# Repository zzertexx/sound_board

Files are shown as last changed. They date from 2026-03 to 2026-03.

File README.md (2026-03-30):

# Soundboard — 16-key Macropad

A custom 16-key macropad built with a Seeed Studio XIAO RP2040, per-key LEDs, and a 0.91" OLED display. Made for [Hack Club](https://hackclub.com/).

---

## Features

- 16 MX-compatible switches in a 4×4 matrix
- Per-key SK6812 MINI-E RGB LEDs
- 0.91" OLED display
- Seeed Studio XIAO RP2040 microcontroller
- QMK firmware
- 3D printed case with sandwitch mounting

---

## Bill of Materials

| Component | Quantity |
|---|---|
| Seeed Studio XIAO RP2040 | 1 |
| MX-style switches | 16 |
| 1N4148 diodes | 16 |
| SK6812 MINI-E LEDs | 16 |
| 0.91" OLED display | 1 |
| DSA white blank keycaps | 16 |
| Resistor 330 ohms | 1 |
| M3x16mm screws | 4 |
| M3x5x4mm heatset inserts | 4 |

---

## Pin Assignment

| Pin | Signal |
|---|---|
| GP0 (PA02) | Row 0 |
| GP1 (PA4) | Row 1 |
| GP2 (PA10) | Row 2 |
| GP3 (PA11) | Row 3 |
| GP4 (PA8 SDA) | OLED SDA |
| GP5 (PA9 SCL) | OLED SCL |
| GP6 (PB08) | Column 0 |
| GP7 (PB09) | Column 1 |
| GP8 (PA7 SCK) | Column 2 |
| GP9 (PA5 MISO) | Column 3 |
| GP10 (PA6 MOSI) | LED Data |

---

## Schematic & PCB

Designed in KiCad 9.0. All source files are in the PCB directory.

- 4×4 keyboard matrix with diodes
- SK6812 MINI-E LEDs placed on bottom layer under each switch
- OLED connected via I2C
- Resistor on GP10 rail for LED stability

---

## Images

sch
pcb
case
pad

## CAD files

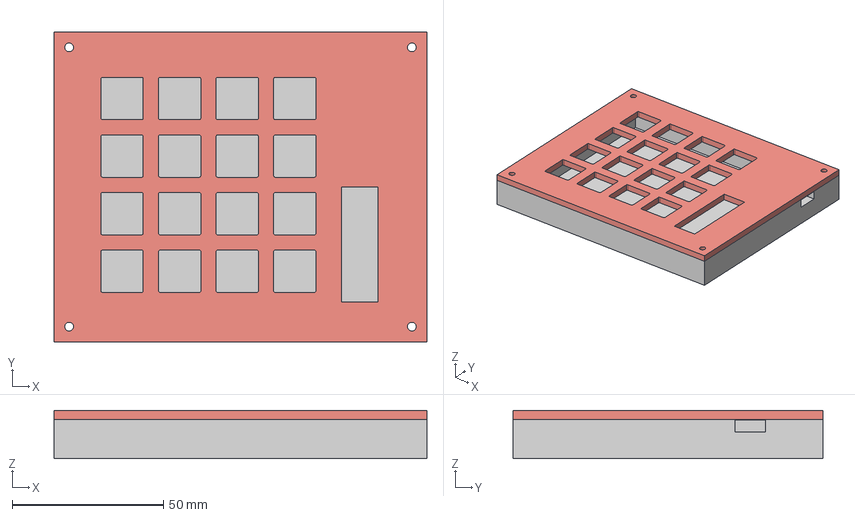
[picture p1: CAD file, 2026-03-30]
CAD/SoundPad.v1.step
123.4 x 102.4 x 16.0 mm

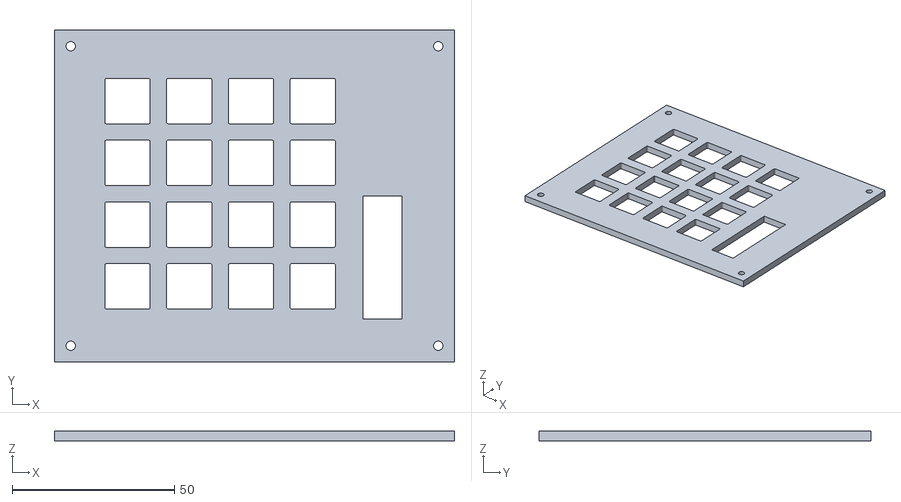
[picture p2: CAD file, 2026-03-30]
production/Plate.stl
123.4 x 102.4 x 3.00

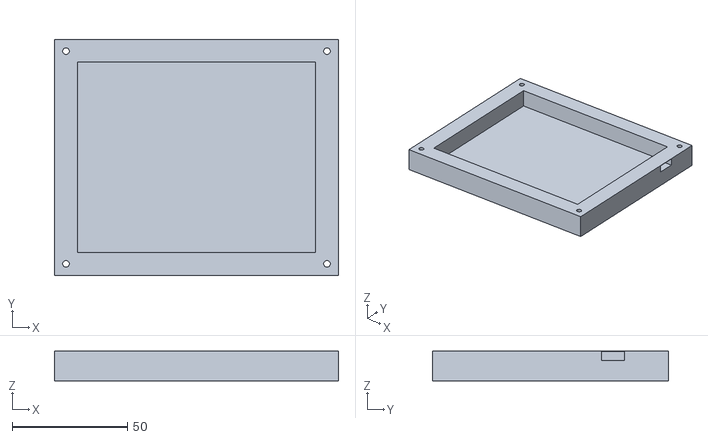
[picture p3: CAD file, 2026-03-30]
production/caseBody.stl
123.4 x 102.4 x 13.0

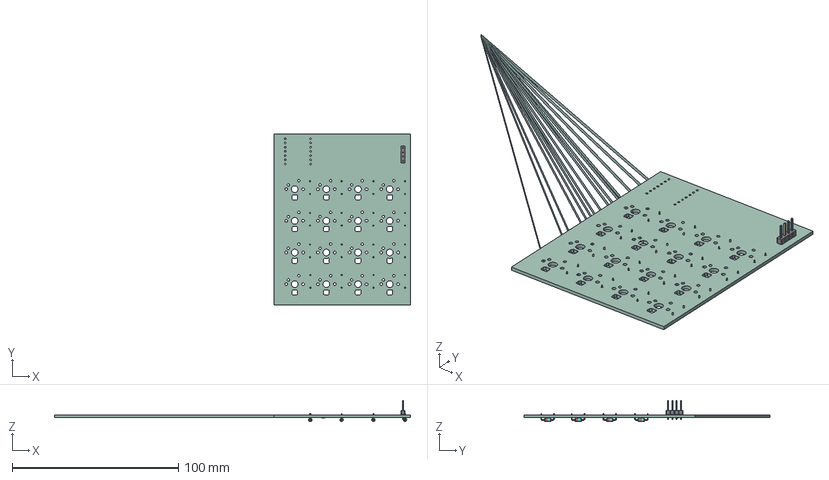
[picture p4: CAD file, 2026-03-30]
production/pcb.step
214.2 x 148.0 x 12.7 mm
PinHeader_1x04_P2.54mm_Vertical
D_DO-35_SOD27_P7.62mm_Horizontal x 16
R_0805_2012Metric
soundboard_PCB

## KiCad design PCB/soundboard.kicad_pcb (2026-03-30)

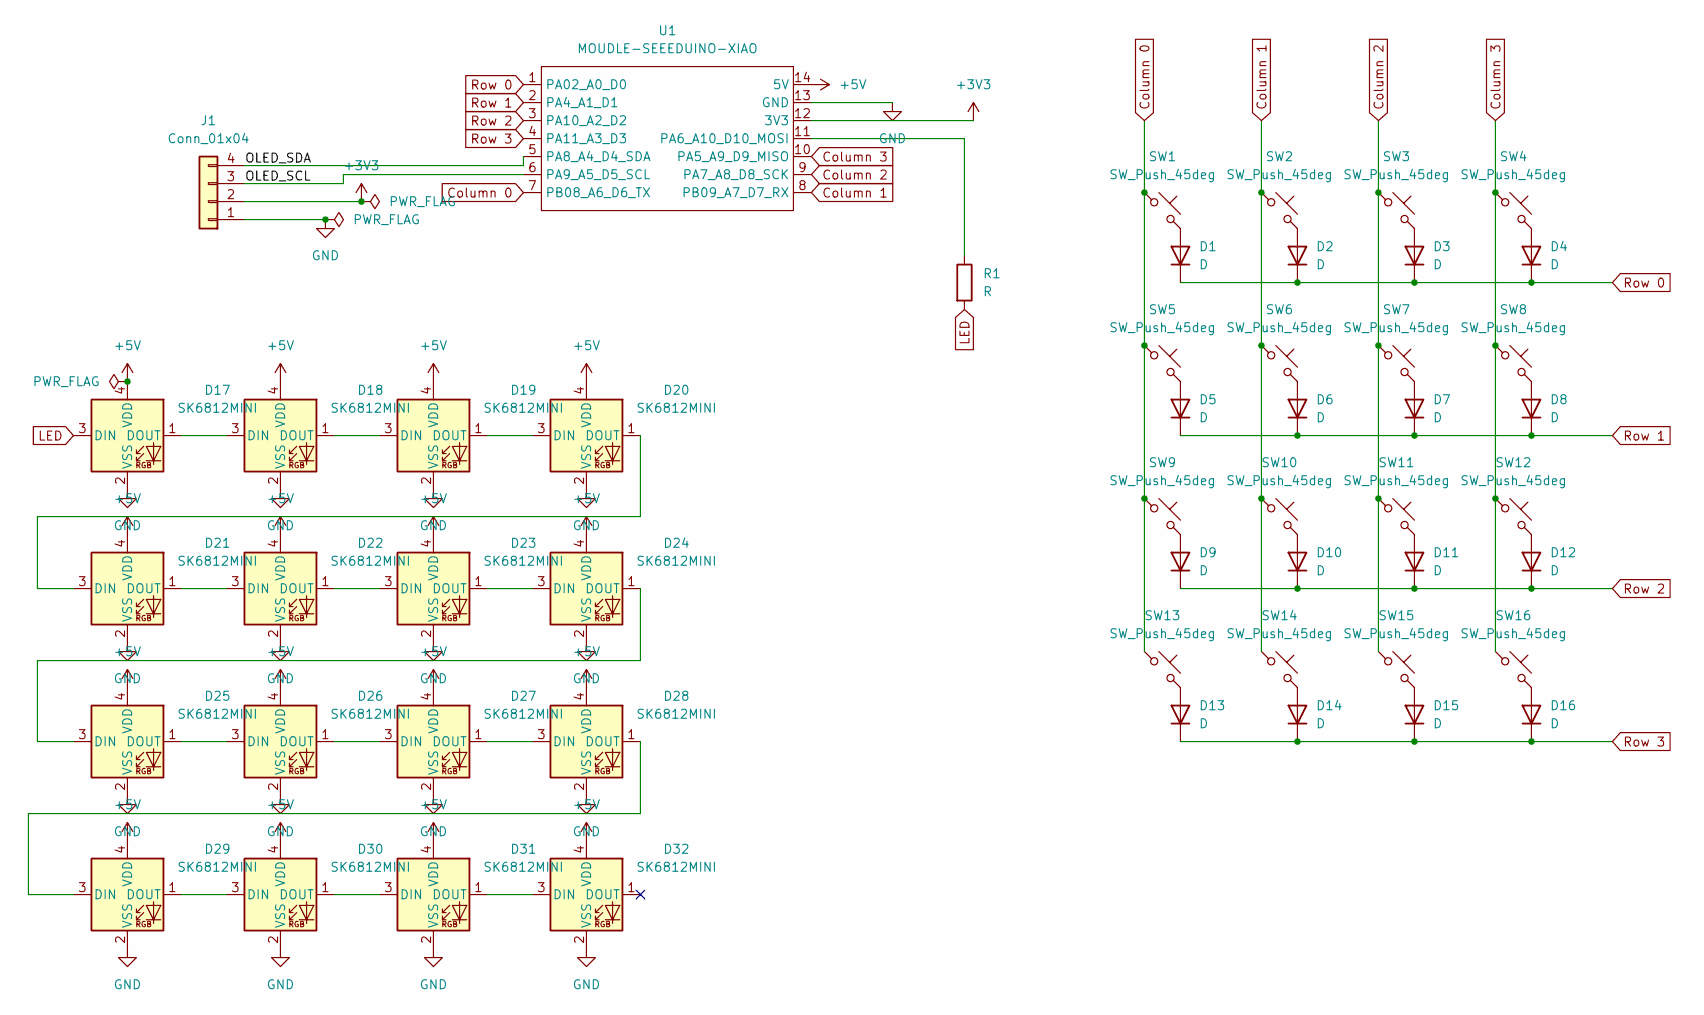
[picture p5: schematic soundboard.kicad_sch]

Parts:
D1, D2, D3, D4, D5, D6, D7, D8, D9, D10, D11, D12, D13, D14, D15, D16: D; D_DO-35_SOD27_P7.62mm_Horizontal
D17, D18, D19, D20, D21, D22, D23, D24, D25, D26, D27, D28, D29, D30, D31, D32: SK6812MINI; SK6812MINI-E_fixed
J1: Conn_01x04; PinHeader_1x04_P2.54mm_Vertical
R1: R; R_0805_2012Metric
SW1, SW2, SW3, SW4, SW5, SW6, SW7, SW8, SW9, SW10, SW11, SW12, SW13, SW14, SW15, SW16: SW_Push_45deg; SW_Cherry_MX_1.00u_PCB
U1: MOUDLE-SEEEDUINO-XIAO; XIAO-Generic-Hybrid-14P-2.54-21X17.8MM

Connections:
+3V3: J1.2, U1.12 (3V3)
+5V: D17.4 (VDD), D18.4 (VDD), D19.4 (VDD), D20.4 (VDD), D21.4 (VDD), D22.4 (VDD), D23.4 (VDD), D24.4 (VDD), D25.4 (VDD), D26.4 (VDD), D27.4 (VDD), D28.4 (VDD), D29.4 (VDD), D30.4 (VDD), D31.4 (VDD), D32.4 (VDD), U1.14 (5V)
/OLED_SCL: J1.3, U1.6 (PA9_A5_D5_SCL)
/OLED_SDA: J1.4, U1.5 (PA8_A4_D4_SDA)
Column 0: SW1.1, SW5.1, SW9.1, SW13.1, U1.7 (PB08_A6_D6_TX)
Column 1: SW2.1, SW6.1, SW10.1, SW14.1, U1.8 (PB09_A7_D7_RX)
Column 2: SW3.1, SW7.1, SW11.1, SW15.1, U1.9 (PA7_A8_D8_SCK)
Column 3: SW4.1, SW8.1, SW12.1, SW16.1, U1.10 (PA5_A9_D9_MISO)
GND: D17.2 (VSS), D18.2 (VSS), D19.2 (VSS), D20.2 (VSS), D21.2 (VSS), D22.2 (VSS), D23.2 (VSS), D24.2 (VSS), D25.2 (VSS), D26.2 (VSS), D27.2 (VSS), D28.2 (VSS), D29.2 (VSS), D30.2 (VSS), D31.2 (VSS), D32.2 (VSS), J1.1, U1.13 (GND)
LED: D17.3 (DIN), R1.2
unnamed: D1.2 (A), SW1.2
unnamed: D2.2 (A), SW2.2
unnamed: D3.2 (A), SW3.2
unnamed: D4.2 (A), SW4.2
unnamed: D5.2 (A), SW5.2
unnamed: D6.2 (A), SW6.2
unnamed: D7.2 (A), SW7.2
unnamed: D8.2 (A), SW8.2
unnamed: D9.2 (A), SW9.2
unnamed: D10.2 (A), SW10.2
unnamed: D11.2 (A), SW11.2
unnamed: D12.2 (A), SW12.2
unnamed: D13.2 (A), SW13.2
unnamed: D14.2 (A), SW14.2
unnamed: D15.2 (A), SW15.2
unnamed: D16.2 (A), SW16.2
unnamed: D17.1 (DOUT), D18.3 (DIN)
unnamed: D18.1 (DOUT), D19.3 (DIN)
unnamed: D19.1 (DOUT), D20.3 (DIN)
unnamed: D20.1 (DOUT), D21.3 (DIN)
unnamed: D21.1 (DOUT), D22.3 (DIN)
unnamed: D22.1 (DOUT), D23.3 (DIN)
unnamed: D23.1 (DOUT), D24.3 (DIN)
unnamed: D24.1 (DOUT), D25.3 (DIN)
unnamed: D25.1 (DOUT), D26.3 (DIN)
unnamed: D26.1 (DOUT), D27.3 (DIN)
unnamed: D27.1 (DOUT), D28.3 (DIN)
unnamed: D28.1 (DOUT), D29.3 (DIN)
unnamed: D29.1 (DOUT), D30.3 (DIN)
unnamed: D30.1 (DOUT), D31.3 (DIN)
unnamed: D31.1 (DOUT), D32.3 (DIN)
unnamed: R1.1, U1.11 (PA6_A10_D10_MOSI)
Row 0: D1.1 (K), D2.1 (K), D3.1 (K), D4.1 (K), U1.1 (PA02_A0_D0)
Row 1: D5.1 (K), D6.1 (K), D7.1 (K), D8.1 (K), U1.2 (PA4_A1_D1)
Row 2: D9.1 (K), D10.1 (K), D11.1 (K), D12.1 (K), U1.3 (PA10_A2_D2)
Row 3: D13.1 (K), D14.1 (K), D15.1 (K), D16.1 (K), U1.4 (PA11_A3_D3)

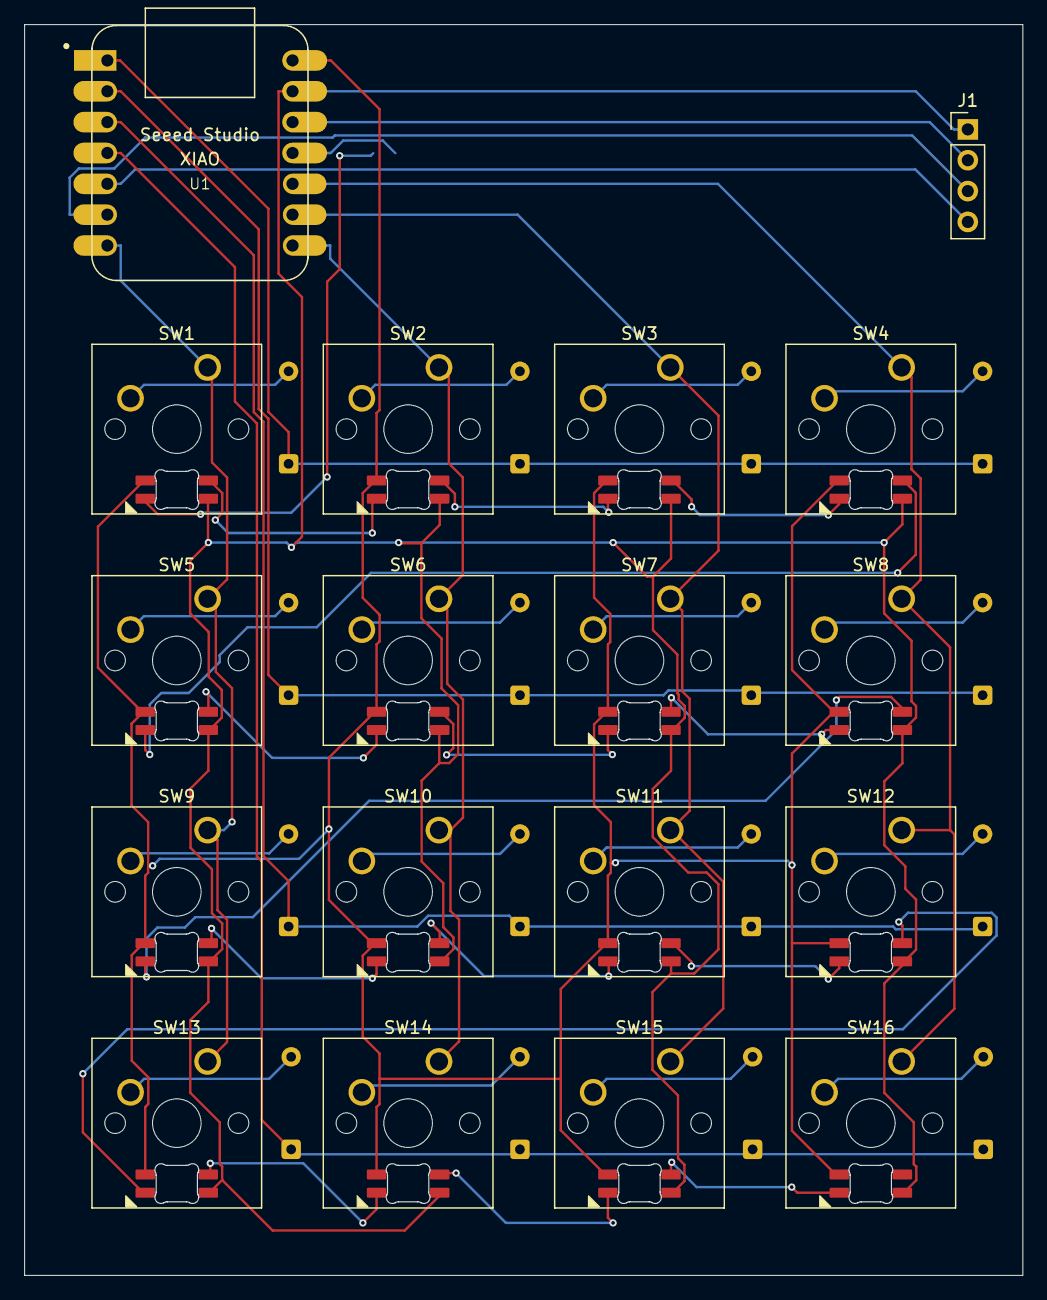
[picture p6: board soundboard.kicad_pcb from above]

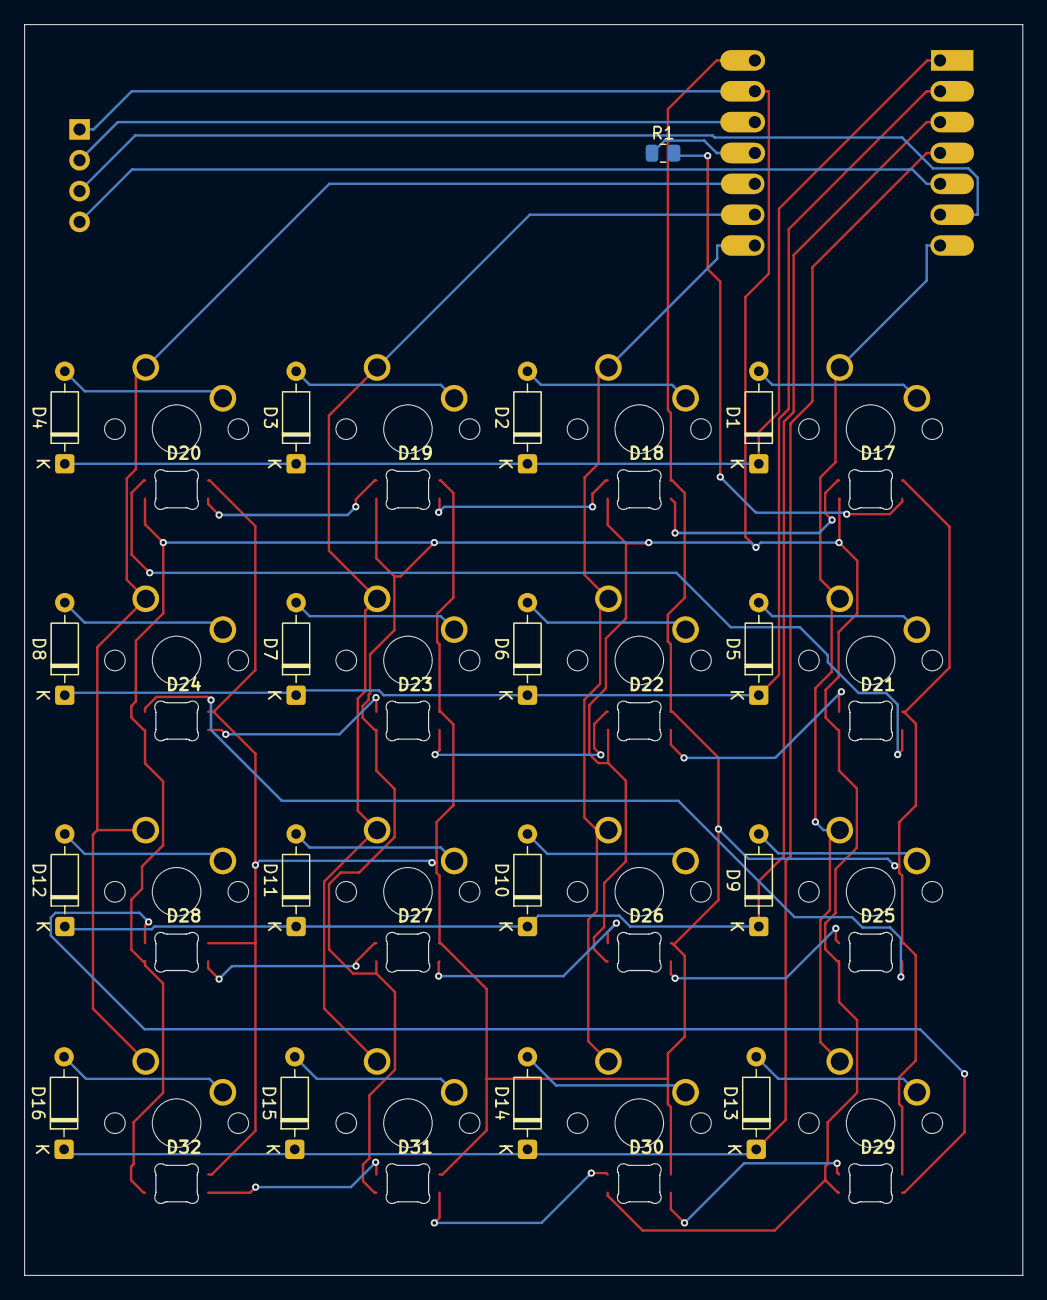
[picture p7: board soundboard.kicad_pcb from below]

Board: 2 copper layers, 82.2 x 103.0 mm, 51 parts (33 on the bottom side), 46 nets.

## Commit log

2026-03-23 Initialize project
    [soundboard.kicad_pcb, soundboard.kicad_sch]
2026-03-23 finished KiCad
    [soundboard.kicad_pcb, soundboard.kicad_sch]
